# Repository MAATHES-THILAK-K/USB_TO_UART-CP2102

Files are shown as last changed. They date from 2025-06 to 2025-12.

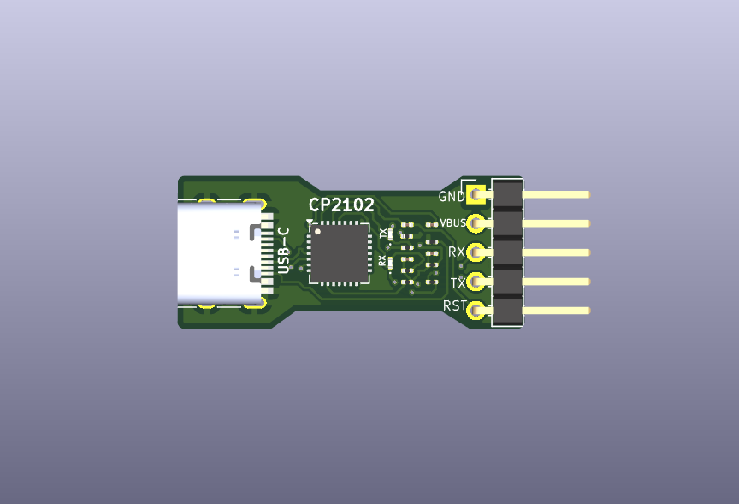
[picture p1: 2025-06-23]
Images/FRONT_VIEW.png

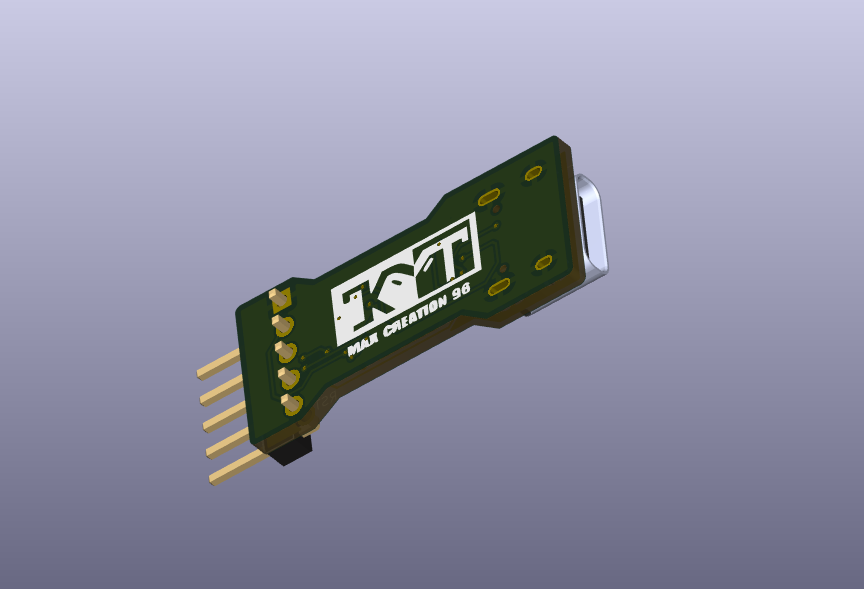
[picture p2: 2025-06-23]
Images/BACK_VIEW.png

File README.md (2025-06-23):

# USB_TO_UART-CP2102

This is a simple and compact USB to UART (serial) converter board designed using the **CP2102 IC** from **Silicon Labs**, with a USB-C input interface. The board was created in **KiCad** and is suitable for use in embedded system development, serial debugging, or programming microcontrollers like STM32, ESP32, Arduino, and more.

## 🔍 About the CP2102

The **CP2102** is a popular single-chip USB to UART bridge manufactured by **Silicon Labs**. It integrates a USB 2.0 transceiver, a crystal-less oscillator, EEPROM, and UART logic in one compact package, making it ideal for simple, low-cost serial communication with PCs or other USB hosts.

### 💡 Where It's Commonly Used

- USB serial debug tools
- Microcontroller bootloader interfaces
- Firmware flashing tools for ESP8266 / ESP32
- Industrial sensor-to-PC interfaces
- USB-based serial consoles (Linux serial TTY access)

---

## 🔗 Features

- USB to UART bridge using **CP2102**
- USB-C connector for modern device compatibility
- 0603 SMD components for compact layout
- Designed using KiCad 6+
- Gerbers ready for fabrication

---

| File/Folder  | Description |
| --- | --- |
| `.kicad_pro` | KiCad project file (project configuration) |
| `.kicad_sch` | Schematic file (circuit design) |
| `.kicad_pcb` | PCB layout file (2D + 3D design of the board) |
| `gerbers/` | Folder containing Gerber files and drill data for PCB fabrication |
| `.step` | 3D model of the assembled PCB for enclosure design and mechanical CAD usage |

---

## ⚙️ Comparison with Other USB-to-UART Chips

| Chip | Manufacturer | Max Baud Rate | Supply Voltage | Notes |
|---|---|---|---|---|
| **CP2102**  | Silicon Labs | ~1 Mbps | 3.3V or 5V | Reliable, widely supported |
| CH340G | WCH (China) | ~921.6 kbps | 5V | Cheap, needs driver on Windows |
| FT232RL | FTDI | ~3 Mbps | 3.3V / 5V | Expensive but robust and driver-friendly |
| PL2303 | Prolific | ~1 Mbps | 3.3V / 5V | Less reliable in some OS versions |

> 💬 The **CP2102** offers a good balance of **cost, stability, and driver support** (native support in Windows, Linux, macOS). It is more stable than CH340G, and more affordable than FT232RL.

---

## 🏗️ Applications

- Serial console access for Linux/Raspberry Pi
- Programming ESP8266/ESP32 boards
- USB-based microcontroller bootloader communication
- Debugging UART output of embedded systems

---

## 📌 Notes

- TX, RX, GND, 3.3V/5V, and DTR/RTS signals can be broken out depending on layout.
- USB-C connector provides better mechanical strength than micro-USB.
- LDO regulator is optional; useful if powering external 3.3V peripherals.

---

## 📤 License

This hardware design is open source and released under the **MIT License**. You are free to use, modify, and distribute it.

---

## 🖼️ Preview

3d Images are added with FRONT,BACK,and ISOMETRIC views.

---
🔗 GrabCAD Model (3D STEP File)

Check out the 3D model of this project on my GrabCAD profile:
👉 https://grabcad.com/maathes.thilak-1

You can view, download, and integrate the .STEP file for enclosure development or CAD simulation.

---

## 🤝 Contributions

Feel free to fork, improve, or suggest enhancements via pull requests or issues!

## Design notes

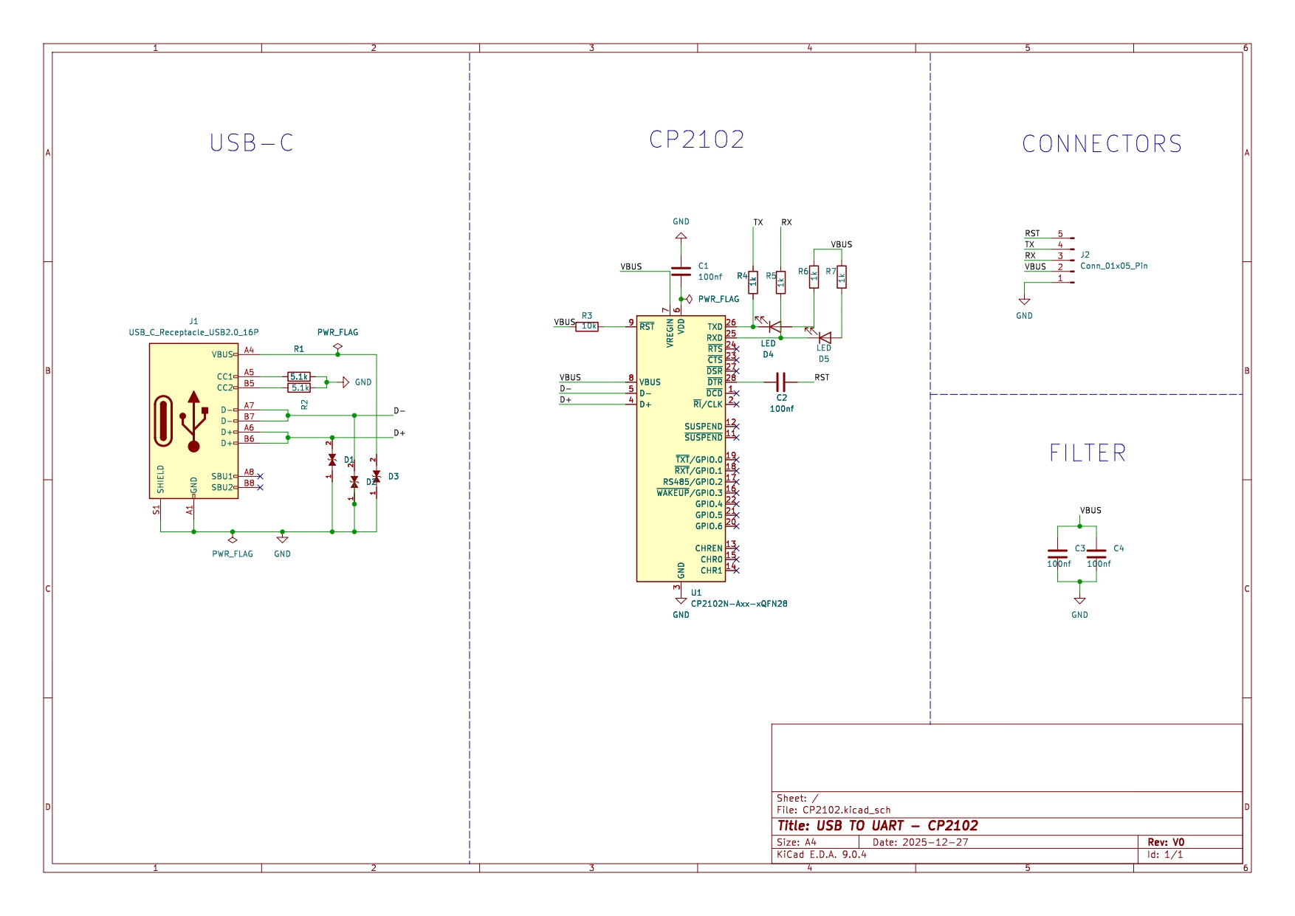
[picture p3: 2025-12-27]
Images/CP2102_page-0001.jpg

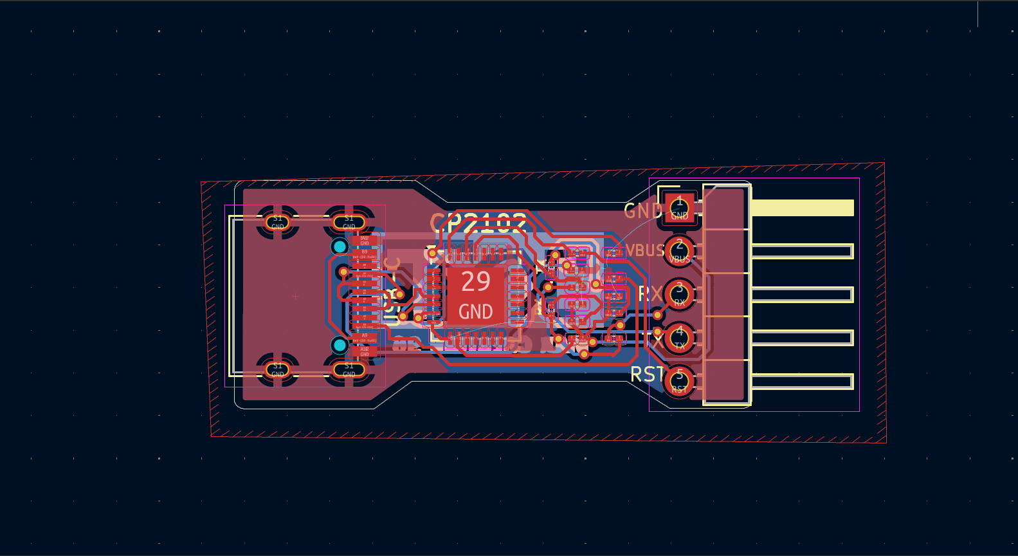
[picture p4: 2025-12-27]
Images/Screenshot from 2025-12-27 13-52-17.png

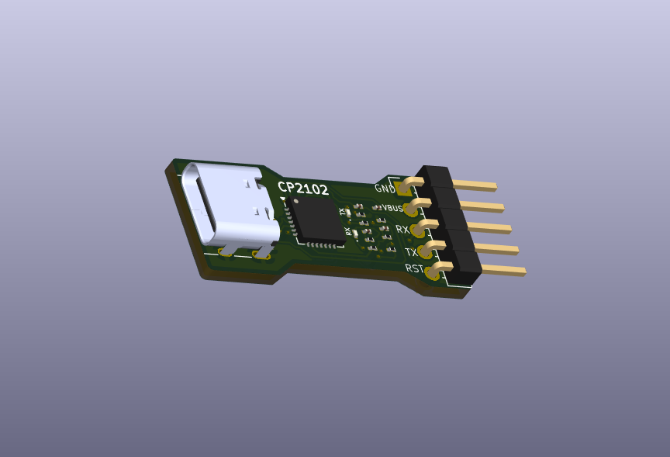
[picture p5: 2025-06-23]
Images/ISOMETRIC_VIEW.png

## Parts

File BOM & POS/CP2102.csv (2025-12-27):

Reference | Qty | Value | DNP | Exclude from BOM | Exclude from Board | Footprint | Datasheet
C1,C2,C3,C4 | 4 | 100nf |  |  |  | Capacitor_SMD:C_0201_0603Metric | ~
D1,D2,D3 | 3 | LESD5D5.0CT1G |  |  |  | LESD5D5.0CT1G:TVS_LESD5D5.0CT1G
D4,D5 | 2 | LED |  |  |  | LED_SMD:LED_0201_0603Metric | ~
J1 | 1 | USB_C_Receptacle_USB2.0_16P |  |  |  | Connector_USB:USB_C_Receptacle_HRO_TYPE-C-31-M-12 | https://www.usb.org/sites/default/files/documents/usb_type-c.zip
J2 | 1 | Conn_01x05_Pin |  |  |  | Connector_PinHeader_2.54mm:PinHeader_1x05_P2.54mm_Horizontal | ~
R1,R2 | 2 | 5.1k |  |  |  | Resistor_SMD:R_0201_0603Metric | ~
R3 | 1 | 10k |  |  |  | Resistor_SMD:R_0201_0603Metric | ~
R4,R5,R6,R7 | 4 | 1k |  |  |  | Resistor_SMD:R_0201_0603Metric | ~
U1 | 1 | CP2102N-Axx-xQFN28 |  |  |  | Package_DFN_QFN:QFN-28-1EP_5x5mm_P0.5mm_EP3.35x3.35mm | https://www.silabs.com/documents/public/data-sheets/cp2102n-datasheet.pdf

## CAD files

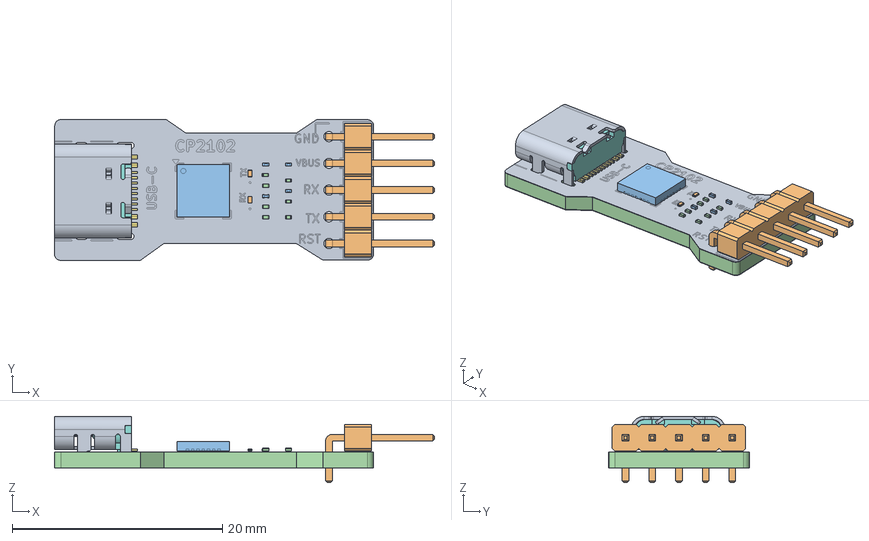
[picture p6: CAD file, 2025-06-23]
CP2102.step
36.1 x 13.4 x 6.31 mm
PinHeader_1x05_P2.54mm_Horizontal
C_0201_0603Metric x 4
R_0201_0603Metric x 7
TYPE-C-31-M-12
LED_0201_0603Metric x 2
QFN-28-1EP_5x5mm_P0.5mm_EP3.35x3.35mm
CP2102_silkscreen
CP2102_soldermask
CP2102_PCB

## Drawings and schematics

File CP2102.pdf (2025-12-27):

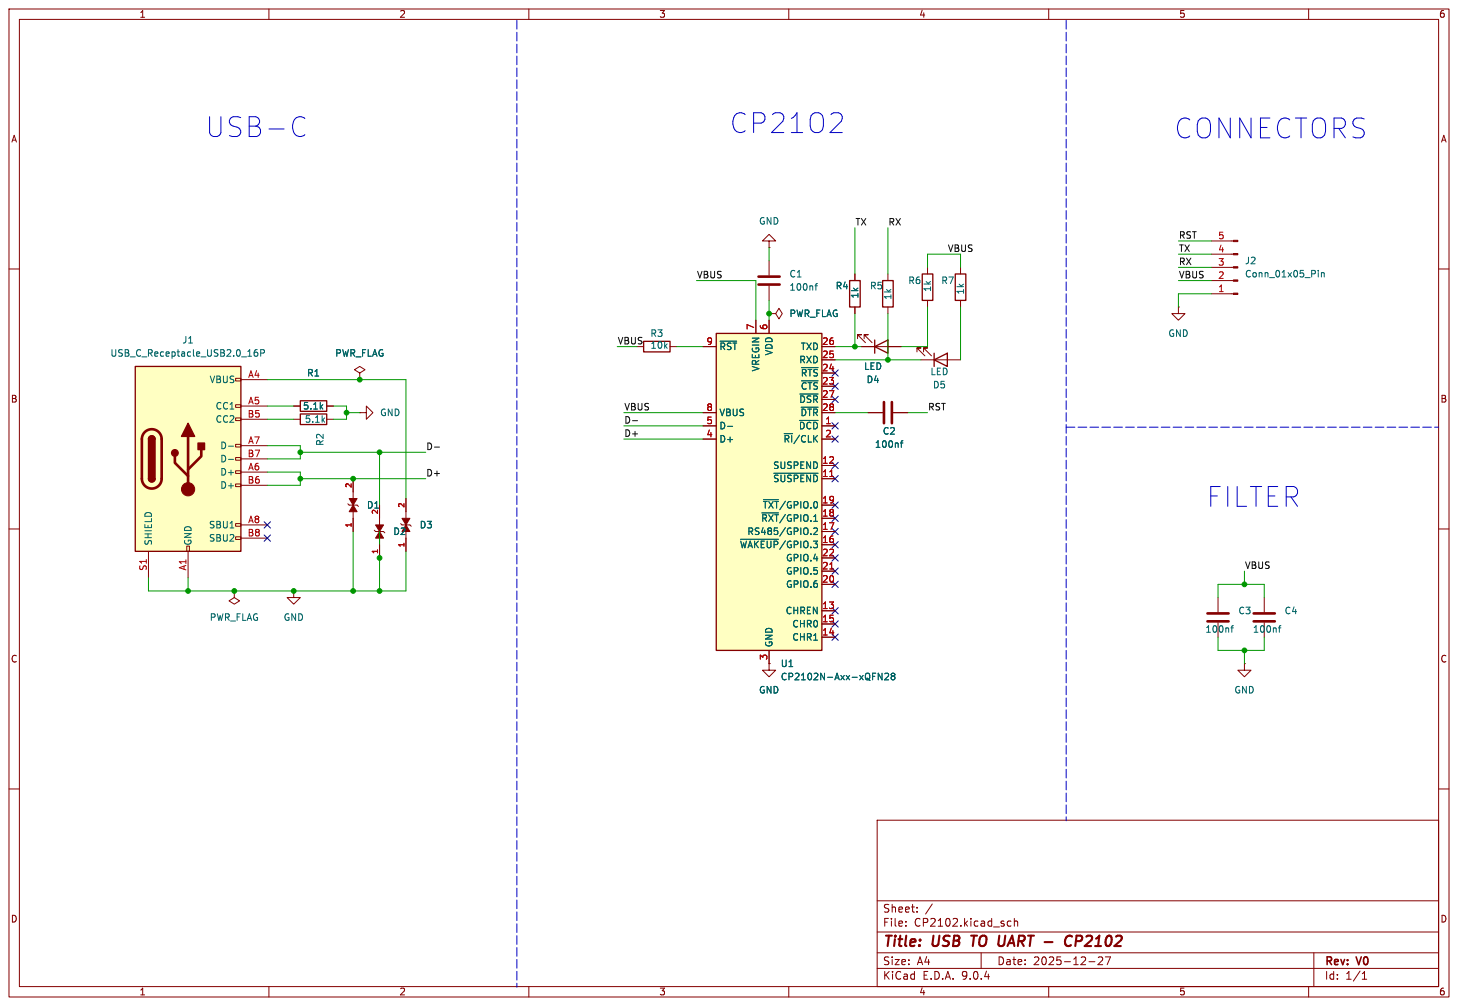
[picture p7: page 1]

3 TXD 26 RXD 25 ~{RTS} 24 ~{CTS} 23 ~{DSR} 27 ~{DTR} 28 ~{DCD}1 ~{RI}/CLK2 SUSPEND 12 ~{SUSPEND}11 ~{TXT}/GPIO.019 ~{RXT}/GPIO.118 RS485/GPIO.2 17 ~{WAKEUP}/GPIO.316 GPIO.4 22 GPIO.5 21 GPIO.6 20 CHREN 13 CHR0 15 CHR1 14 U1 CP2102N-Axx-xQFN28 R1
100nf PWR_FLAG

3 TXD 26 RXD 25 ~{RTS} 24 ~{CTS} 23 ~{DSR} 27 ~{DTR} 28 ~{DCD}1 ~{RI}/CLK2 SUSPEND 12 ~{SUSPEND}11 ~{TXT}/GPIO.019 ~{RXT}/GPIO.118 RS485/GPIO.2 17 ~{WAKEUP}/GPIO.316 GPIO.4 22 GPIO.5 21 GPIO.6 20 CHREN 13 CHR0 15 CHR1 14 C2

File: CP2102.kicad_sch Sheet: /
Id: 1/1 Title: USB TO UART - CP2102

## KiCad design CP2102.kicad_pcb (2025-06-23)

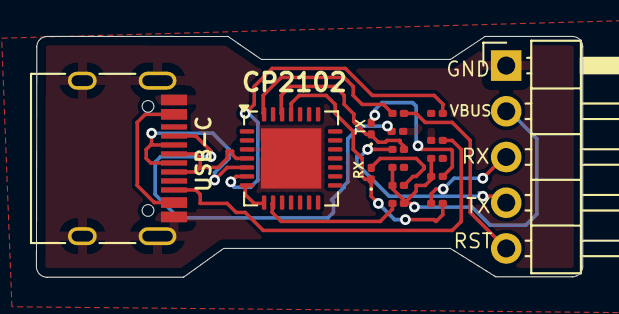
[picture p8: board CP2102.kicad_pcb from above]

Board: 2 copper layers, 30.3 x 13.4 mm, 16 parts (0 on the bottom side), 17 nets.

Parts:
C1, C2, C3, C4: 100nf; C_0201_0603Metric
D4, D5: LED; LED_0201_0603Metric
J1: USB_C_Receptacle_USB2.0_16P; USB_C_Receptacle_HRO_TYPE-C-31-M-12
J2: Conn_01x05_Pin; PinHeader_1x05_P2.54mm_Horizontal
R1, R2: 5.1k; R_0201_0603Metric
R3: 10k; R_0201_0603Metric
R4, R5, R6, R7: 1k; R_0201_0603Metric
U1: CP2102N-Axx-xQFN28; QFN-28-1EP_5x5mm_P0.5mm_EP3.35x3.35mm

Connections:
/D+: J1.A6 (D+), J1.B6 (D+), U1.4 (D+)
/D-: J1.A7 (D-), J1.B7 (D-), U1.5 (D-)
/RST: C2.2, J2.5
/RX: J2.3, R5.1
/TX: J2.4, R4.1
/VBUS: C3.1, C4.1, J2.2, R3.1, R6.1, R7.1, U1.7 (VREGIN), U1.8 (VBUS)
GND: C1.1, C3.2, C4.2, J1.A1 (GND), J1.A12 (GND), J1.B1 (GND), J1.B12 (GND), J1.S1 (SHIELD), J2.1, R1.2, R2.1, U1.3 (GND), U1.29 (GND)
unnamed: J1.A4 (VBUS), J1.A9 (VBUS), J1.B4 (VBUS), J1.B9 (VBUS)
unnamed: D4.2 (A), R6.2
unnamed: D4.1 (K), R4.2, U1.26 (TXD)
unnamed: D5.2 (A), R7.2
unnamed: D5.1 (K), R5.2, U1.25 (RXD)
unnamed: J1.A5 (CC1), R1.1
unnamed: J1.B5 (CC2), R2.2
unnamed: C1.2, U1.6 (VDD)
unnamed: C2.1, U1.28 (~DTR)
unnamed: R3.2, U1.9 (~RST)

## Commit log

2025-06-23 Gerber files for the CP2120 USB TO UART Uploaded
    [CP2102-B_Cu.gbr, CP2102-B_Mask.gbr, CP2102-B_Paste.gbr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]
2025-06-23 Uploaded the 3d View of the PCB
2025-06-23 3D model for CP2102 was added - STEP file
    [CP2102.step]
